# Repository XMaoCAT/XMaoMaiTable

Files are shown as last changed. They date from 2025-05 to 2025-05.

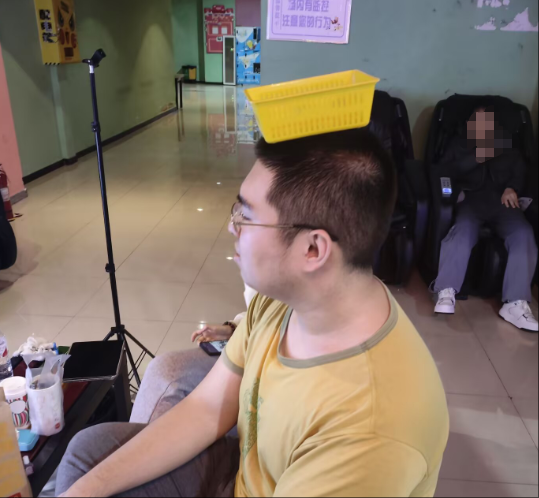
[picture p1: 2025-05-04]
wechat_2025-05-05_020822_078.png

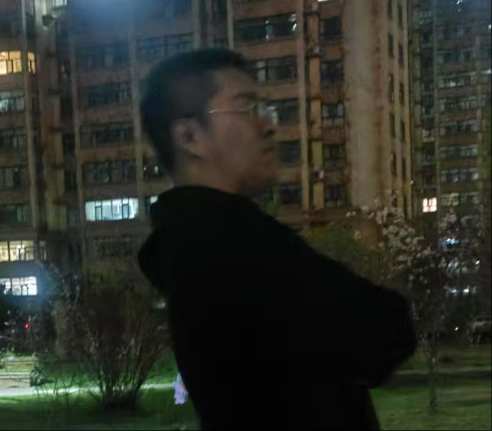
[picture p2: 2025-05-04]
1212121211.png

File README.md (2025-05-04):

# XMaoMaiTable
一个关于MaiMaiDX的手台方案
------------------------------------------------------------
本方案基于晶台的方案进行改进(可能是古老的晶台方案)

台子的制作参考UP主：https://space.bilibili.com/286413610

UP主视频合集：https://space.bilibili.com/286413610/lists/2365759?type=season

本方案采用ESP32-S3,XIAO SAMD21,MPR121实现
需要用两条数据线驱动手台
下面为实装教程
--------------------------------------------------------------
首先，你需要两个三角方刚架，本方案采用20x20的方刚来定制，尺寸图如下



切割时，再找师傅要  5根【710mm】，一根【750mm】的方钢，和一根【750mm】的角铁

成品如图： (给师傅看+自己在现场指导 应该问题不大)



其中：蓝色和黄色代表750mm的一根 方钢 和一根 角铁 。

关于固定显示器：
请在第一节或者第二节方钢焊接好后将显示器放置在上面对准，对准后打孔固定。
如果孔位太高或太低，可考虑要一块钢板，在钢板上打孔固定显示器后，将钢板钉在方钢上，起到固定效果。


角铁的固定位置参考：


关于750mm的方钢
-
这节方钢主要用于给前触摸按键的板子做支撑，所以位置由显示器的底边来决定，请您根据实际情况对准后使用钻打孔后使用螺丝固定即可。

影响位置的因素：显示屏底边高矮无法确定

关于ITO的粘贴和架构的粘贴
-
您可以购买免钉胶粘贴金属板，密度板，和玻璃。

金属板，密度板 和 玻璃板 的文件您可以在文件列表内找到并下载

个人推荐2mm金属板+8mm密度板
玻璃可以找淘宝，PDD 来定制，要5mm白钢化玻璃

ITO的粘贴和定位：
您需要购买一张 40欧姆 至少30x30cm 的ITO模(尽量要带背胶)
然后打印【两张】 "贴片参考" 一张正常，一张镜像
其中: 正常的是用来辅助裁剪ITO的，镜像是粘到屏幕前 给ITO粘贴做参考的。
a891f49ffdc61b3640403c697c1059ee
这里我由于没镜像导致判定区全反了（） 也是吸取教训了

关于按键程序
-
正常的光眼一般由这种信号传输格式，您购买按键组装时请留意一下，方便您直接安装和测试按键避免因为接反导致的按键疯狂触发或者按着没反应。


关于材料购买
-----------------------------
方钢和角钢去定制  根据您找的店家来决定（多问问 会有惊喜的）

两根USB线 （如担心干扰可以买一个USB滤波器给XIAO SAMD21用）

2.5m 左右的四芯屏蔽线（MPR和XIAO之间的连接使用）

铜箔 （粘在ITO末端增强信号）

屏蔽胶带 （如有引出线重叠的位置，可以贴上防止信号干扰）

2m 镀银一芯线 （用于ITO和mpr121设备间的连接，如果感觉没必要，也可以买一排杜邦线替代）

醋酸胶带 （最简谱的 粘贴导线的办法）

源地 YD-ESP32-S3 x1

mpr121 x4 （有概率是坏的，可以多买几个备用）

Xiao SAMD21G18 x1

密度板

金属板

玻璃板

ITO 40欧 30x30cm

舞萌按键

光眼等等

杜邦线 母对母 一排 （按键用）

杜邦线 公对母 一排 （按键用）

---------------------------------------------------------------------------------

 恭喜您看完啦~ 相信你一定可以手搓一台ADX的喵~ 
 如果有我没补充的 请去观看UP主的视频，包含详细的制作流程
 哦对了，关于XIAO的焊接我没有写，请你观看我指向UP主的视频。

关于本项目奇奇怪怪的图片
-
都是舞萌群内的逆天吊图和抽象群友，欢迎做成表情包喵

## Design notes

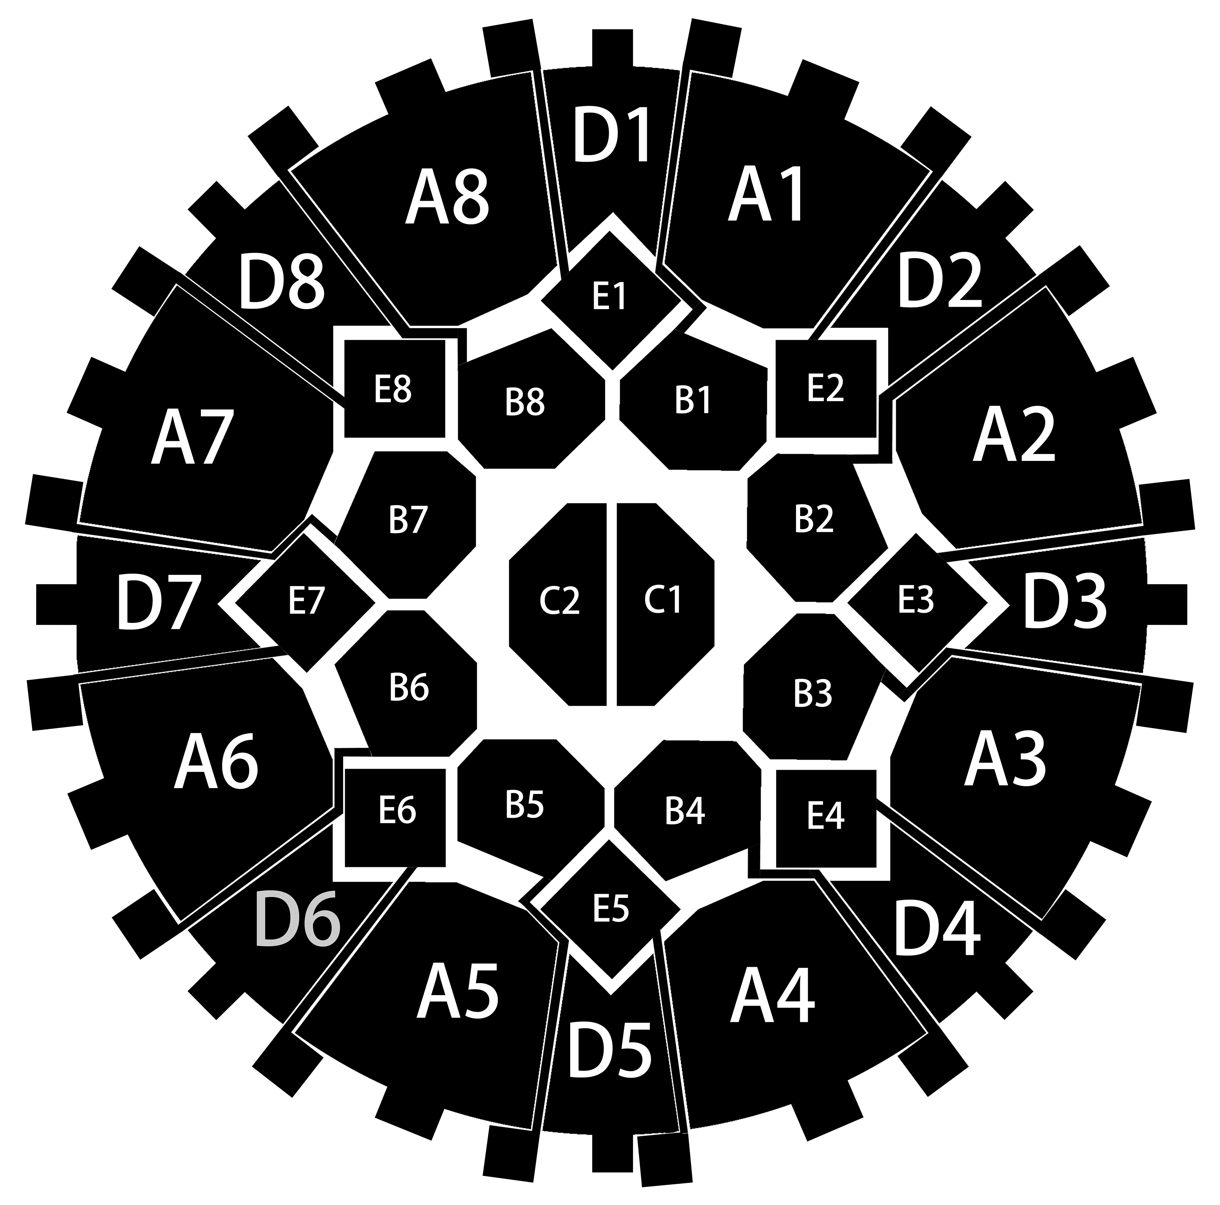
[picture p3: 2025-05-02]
贴片参考.png

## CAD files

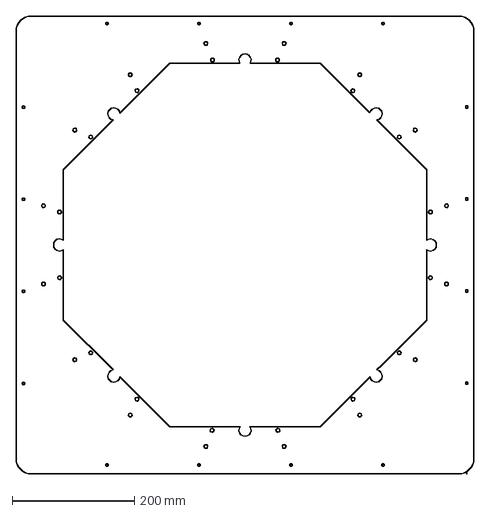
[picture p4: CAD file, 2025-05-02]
密度板.dxf
750.0 x 750.1 mm

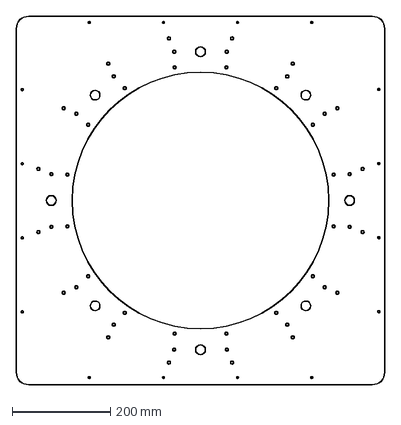
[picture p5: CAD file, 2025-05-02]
金属板.dxf
750.0 x 750.0 mm

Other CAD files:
玻璃.dwg
